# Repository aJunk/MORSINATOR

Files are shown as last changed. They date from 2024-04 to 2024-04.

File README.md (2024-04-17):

# Morsinator

This repository contains the design files and code for the MORSINATOR.
The MORSINATOR is a morse code transceiver developed for application in scout group activities.

## Overview
The MORSINATOR is an RS485-based Hardware interface for transmitting morse code over several hundred meters across twin telecom/telephone wiring.

It does not transmit data, just high and low pulses.

## Future development

The board contains space and components for integrating an ESP32C3 microcontroller. It can Intercept the user input and line output.
It can be used to automate message sending and receiving, coordinate between stations, and more.

Code for it is not finished yet and will be added once in a presentable state.

## License
This project is licensed under the GPLv3.

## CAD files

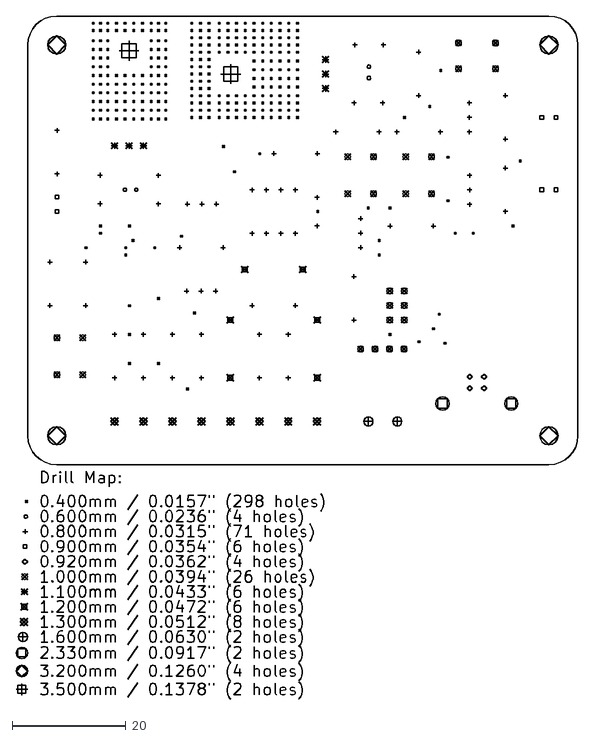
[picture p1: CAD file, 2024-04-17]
board/morsinator-3000/gerbers/morsinator-3000-PTH-drl_map.dxf
98.6 x 119.8

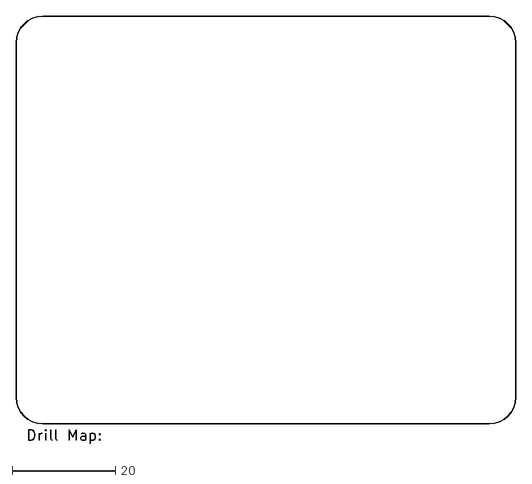
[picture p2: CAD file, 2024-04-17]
board/morsinator-3000/gerbers/morsinator-3000-NPTH-drl_map.dxf
96.5 x 82.6

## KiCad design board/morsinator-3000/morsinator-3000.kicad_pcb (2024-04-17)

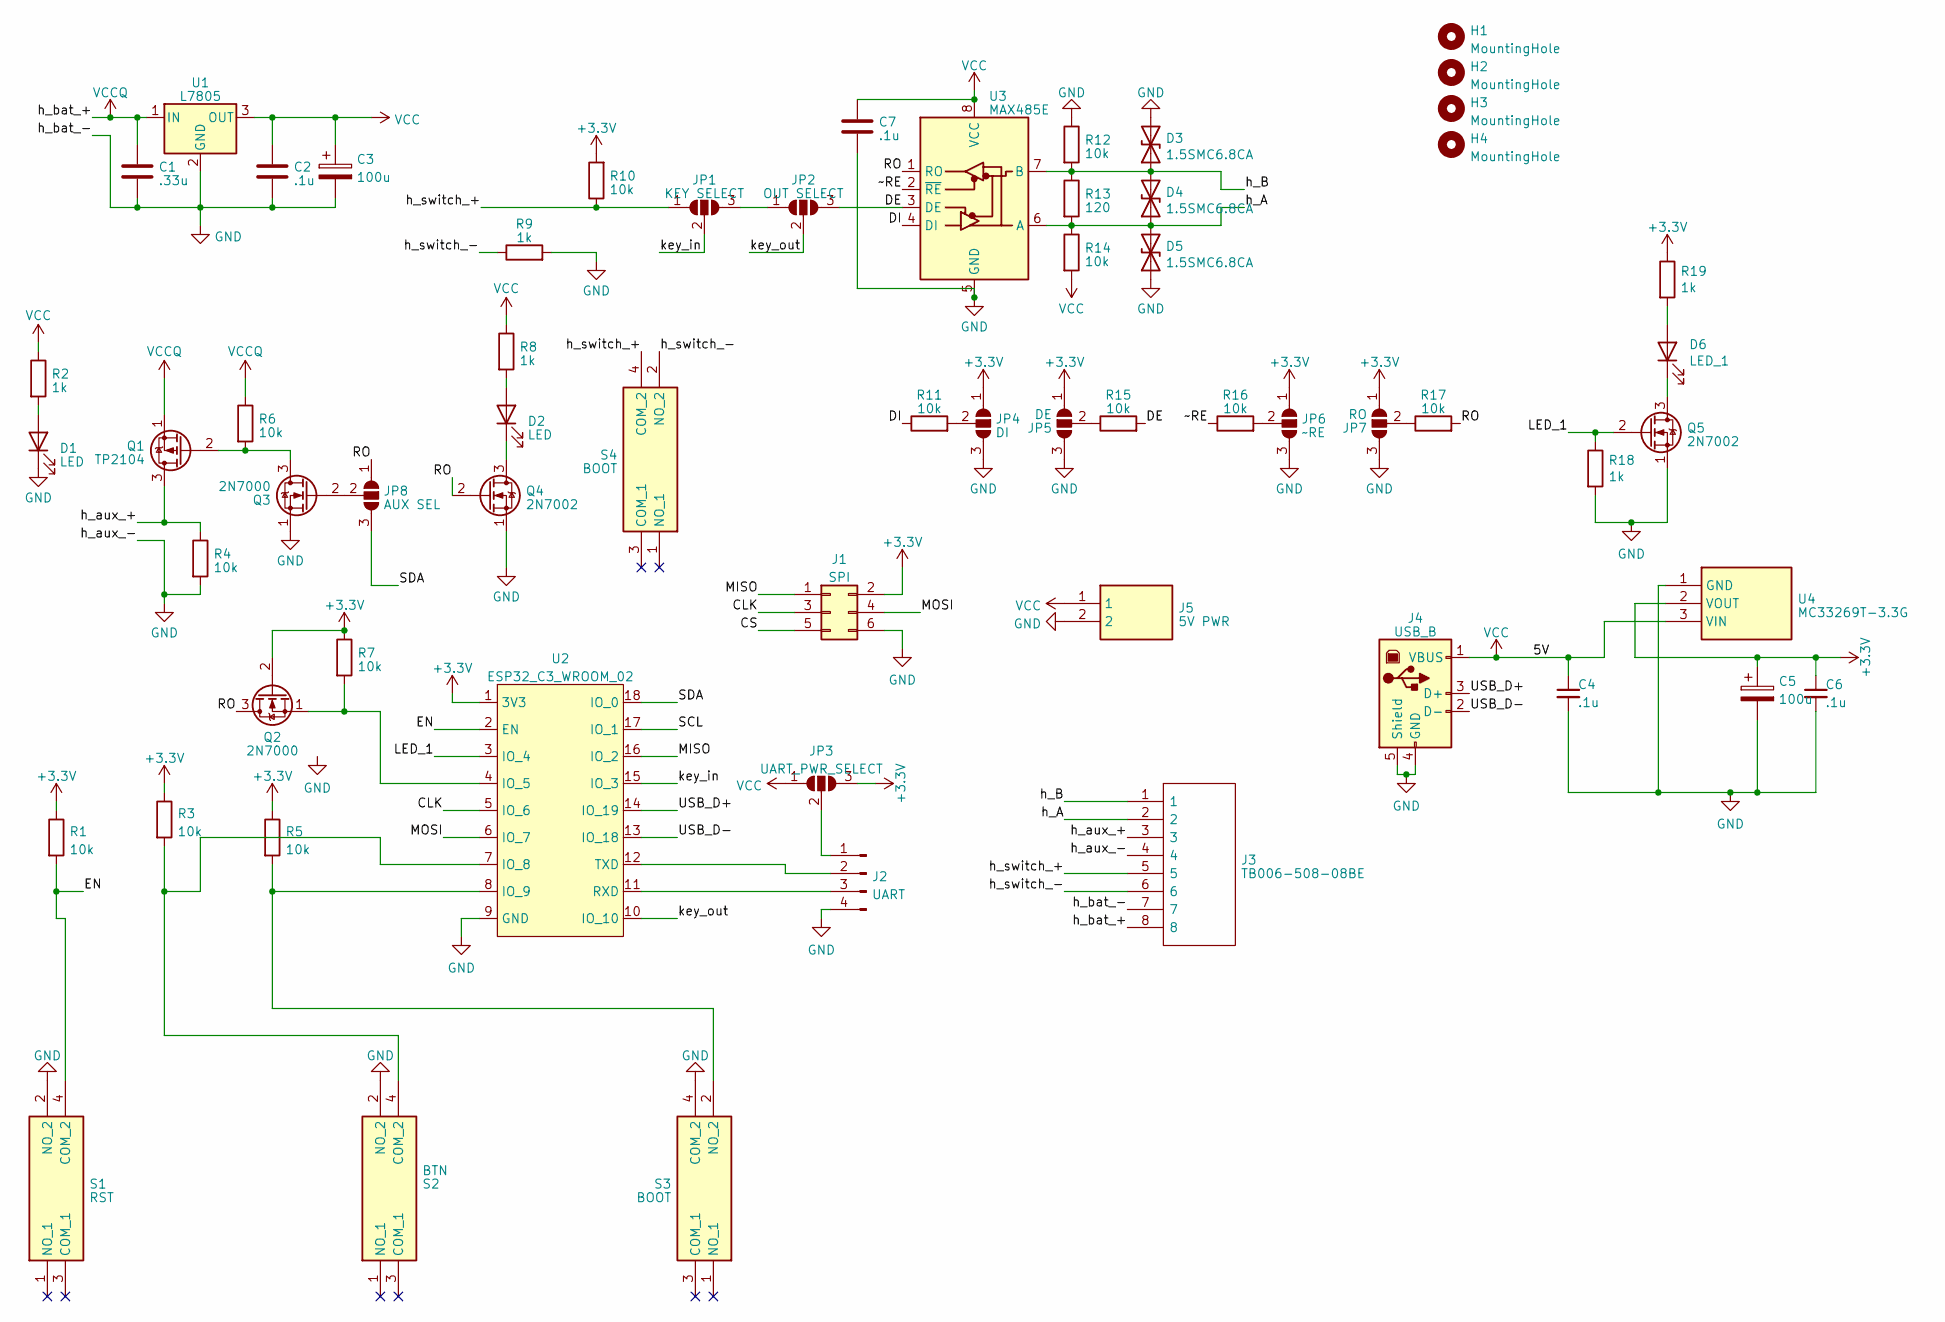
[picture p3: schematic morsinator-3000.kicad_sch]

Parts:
C1: .33u; C_Rect_L7.0mm_W2.5mm_P5.00mm
C2, C4, C6, C7: .1u; C_Rect_L7.0mm_W2.5mm_P5.00mm
C3, C5: 100u; CP_Radial_D4.0mm_P2.00mm
D1, D2: LED; LED_D5.0mm
D3, D4, D5: 1.5SMC6.8CA; D_DO-15_P10.16mm_Horizontal
D6: LED_1; LED_D5.0mm
H1, H2, H3, H4: MountingHole; MountingHole_3.2mm_M3_DIN965_Pad_TopBottom
J1: SPI; PinHeader_2x03_P2.54mm_Vertical
J2: UART; PinHeader_1x04_P2.54mm_Vertical
J3: TB006-508-08BE; TB00650808BE; Mouser Part Number 490-TB006-508-08BE
J4: USB_B; USB_B_OST_USB-B1HSxx_Horizontal
J5: 5V PWR; SHDR2W100P0X508_1X2_1016X1020X1410P; Mouser Part Number 490-TB004-508-02BE
JP1: KEY SELECT; SolderJumper-3_P1.3mm_Open_RoundedPad1.0x1.5mm_NumberLabels
JP2: OUT SELECT; SolderJumper-3_P1.3mm_Open_RoundedPad1.0x1.5mm_NumberLabels
JP3: UART_PWR_SELECT; SolderJumper-3_P1.3mm_Open_RoundedPad1.0x1.5mm_NumberLabels
JP4: DI; SolderJumper-3_P1.3mm_Open_RoundedPad1.0x1.5mm_NumberLabels
JP5: DE; SolderJumper-3_P1.3mm_Open_RoundedPad1.0x1.5mm_NumberLabels
JP6: ~RE; SolderJumper-3_P1.3mm_Open_RoundedPad1.0x1.5mm_NumberLabels
JP7: RO; SolderJumper-3_P1.3mm_Open_RoundedPad1.0x1.5mm_NumberLabels
JP8: AUX SEL; SolderJumper-3_P1.3mm_Open_RoundedPad1.0x1.5mm_NumberLabels
Q1: TP2104; TO-92_Inline_Wide
Q2, Q3: 2N7000; TO-92_Inline_Wide
Q4, Q5: 2N7002; TO-92_Inline_Wide
R1, R3, R4, R5, R6, R7, R10, R11, R12, R14, R15, R16, R17: 10k; R_Axial_DIN0207_L6.3mm_D2.5mm_P7.62mm_Horizontal
R2, R8, R9, R18, R19: 1k; R_Axial_DIN0207_L6.3mm_D2.5mm_P7.62mm_Horizontal
R13: 120; R_Axial_DIN0207_L6.3mm_D2.5mm_P7.62mm_Horizontal
S1: RST; TS026643BK100SCRD; Mouser Part Number 179-TS026643BK100SCR
S2: BTN; TS026643BK100SCRD; Mouser Part Number 179-TS026643BK100SCR
S3, S4: BOOT; TS026643BK100SCRD; Mouser Part Number 179-TS026643BK100SCR
U1: L7805; TO-220-3_Horizontal_TabDown
U2: ESP32_C3_WROOM_02; ESP32C3WROOM02N4
U3: MAX485E; DIP-8_W7.62mm_Socket
U4: MC33269T-3.3G; TO-220-3_Horizontal_TabDown; Mouser Part Number 863-MC33269T-3.3G

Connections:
+3V3: C5.1, C6.1, J1.2, JP3.3 (B), JP4.1 (A), JP5.1 (A), JP6.1 (A), JP7.1 (A), Q2.2 (G), R1.1, R3.1, R5.1, R7.1, R10.2, R19.1, U2.1 (3V3), U4.2 (VOUT)
/CLK: J1.3, U2.5 (IO_6)
/CS: J1.5
/DE: JP2.3 (B), R15.2, U3.3 (DE)
/DI: R11.1, U3.4 (DI)
/EN: R1.2, S1.4 (COM_2), U2.2 (EN)
/LED_1: Q5.2 (G), R18.1, U2.3 (IO_4)
/MISO: J1.1, U2.16 (IO_2)
/MOSI: J1.4, U2.6 (IO_7)
/RO: JP8.1 (A), Q2.3 (D), Q4.2 (G), R17.2, U3.1 (RO)
/SCL: U2.17 (IO_1)
/SDA: JP8.3 (B), U2.18 (IO_0)
/USB_D+: J4.3 (D+), U2.14 (IO_19)
/USB_D-: J4.2 (D-), U2.13 (IO_18)
/h_A: D4.1 (A1), D5.2 (A2), J3.2, R13.2, R14.1, U3.6 (A)
/h_B: D3.1 (A1), D4.2 (A2), J3.1, R12.2, R13.1, U3.7 (B)
/h_aux_+: J3.3, Q1.3 (D), R4.1
/h_switch_+: J3.5, JP1.1 (A), R10.1, S4.4 (COM_2)
/h_switch_-: J3.6, R9.1, S4.2 (NO_2)
/key_in: JP1.2 (C), U2.15 (IO_3)
/key_out: JP2.2 (C), U2.10 (IO_10)
/~RE: R16.1, U3.2 (~RE)
GND: C1.2, C2.2, C3.2, C4.2, C5.2, C6.2, C7.2, D1.1 (K), D3.2 (A2), D5.1 (A1), J1.6, J2.4, J3.4, J3.7, J4.4 (GND), J4.5 (Shield), J5.2, JP4.3 (B), JP5.3 (B), JP6.3 (B), JP7.3 (B), Q3.1 (S), Q4.1 (S), Q5.1 (S), R4.2, R9.2, R12.1, R18.2, S1.2 (NO_2), S2.2 (NO_2), S3.4 (COM_2), U1.2 (GND), U2.9 (GND), U3.5 (GND), U4.1 (GND)
unnamed: D1.2 (A), R2.2
unnamed: D2.2 (A), R8.2
unnamed: D2.1 (K), Q4.3 (D)
unnamed: D6.2 (A), R19.2
unnamed: D6.1 (K), Q5.3 (D)
unnamed: J2.1, JP3.2 (C)
unnamed: J2.2, U2.12 (TXD)
unnamed: J2.3, U2.11 (RXD)
unnamed: JP1.3 (B), JP2.1 (A)
unnamed: JP4.2 (C), R11.2
unnamed: JP5.2 (C), R15.1
unnamed: JP6.2 (C), R16.2
unnamed: JP7.2 (C), R17.1
unnamed: JP8.2 (C), Q3.2 (G)
unnamed: Q1.2 (G), Q3.3 (D), R6.2
unnamed: Q2.1 (S), R7.2, U2.4 (IO_5)
unnamed: R3.2, S2.4 (COM_2), U2.7 (IO_8)
unnamed: R5.2, S3.2 (NO_2), U2.8 (IO_9)
VCC: C2.1, C3.1, C4.1, C7.1, J4.1 (VBUS), J5.1, JP3.1 (A), R2.1, R8.1, R14.2, U1.3 (OUT), U3.8 (VCC), U4.3 (VIN)
VCCQ: C1.1, J3.8, Q1.1 (S), R6.1, U1.1 (IN)

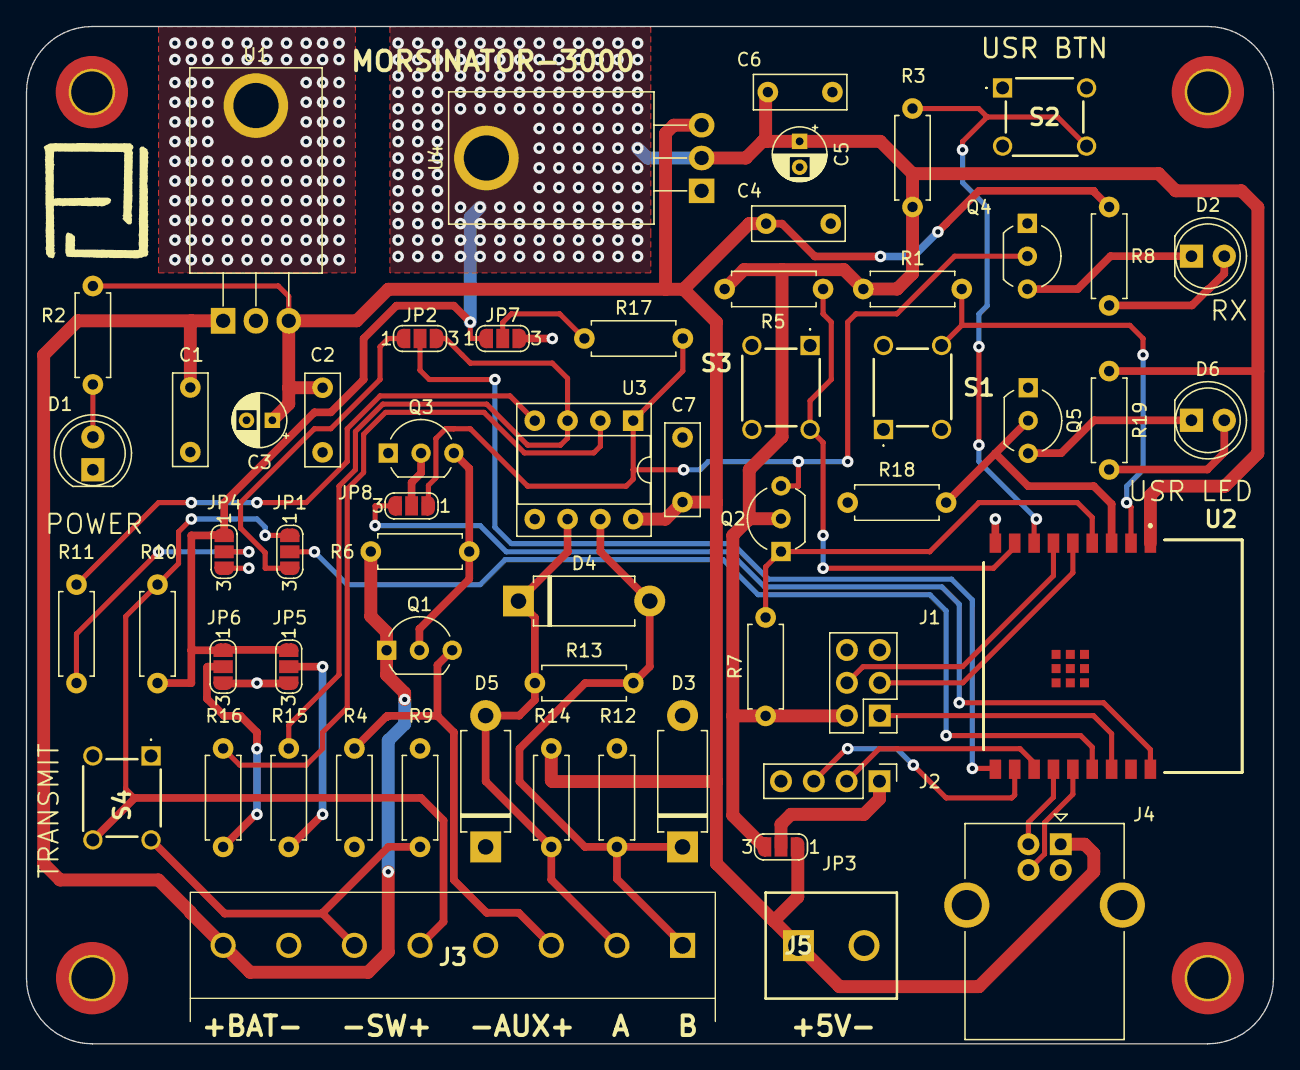
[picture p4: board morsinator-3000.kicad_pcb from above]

Board: 2 copper layers, 96.5 x 78.7 mm, 62 parts (0 on the bottom side), 41 nets.
